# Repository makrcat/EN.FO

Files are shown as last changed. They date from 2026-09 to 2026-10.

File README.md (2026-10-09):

## outdoorsy-gadget

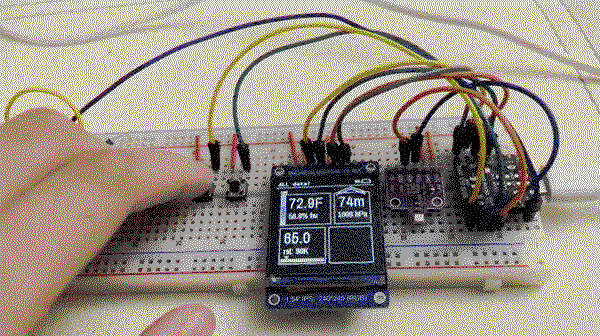
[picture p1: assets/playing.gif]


The **EN.FO** is a personal project for tracking the environment when outdoors. It measures altitude (pressure), temperature, humidity, and air quality through the BME680 chip. And it also has games now :3c

Around the end stages submitted to hack club stardance.

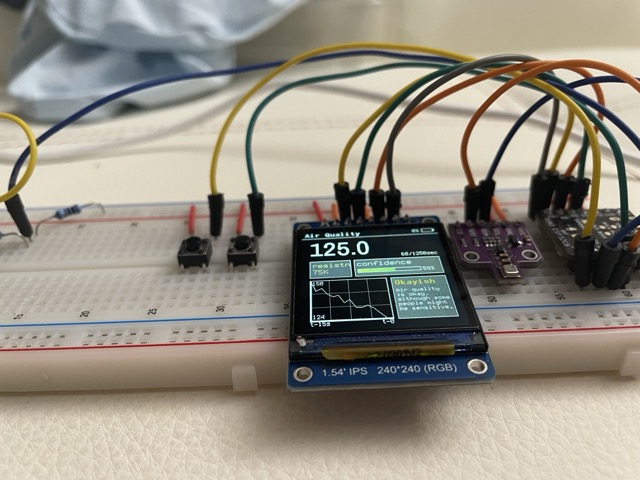
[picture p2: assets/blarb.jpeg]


## Why I made this

I found a BME680 in a store, and I'd seen people making these home weather station setups and using temperature sensors for their first projects. I thought it would be cool to be able to track the weather while outside too, like while hiking or going somewhere without wifi! 

It would be pretty neat to get momentary values from a sensor for the surrounding area instead of looking online.

## CAD models


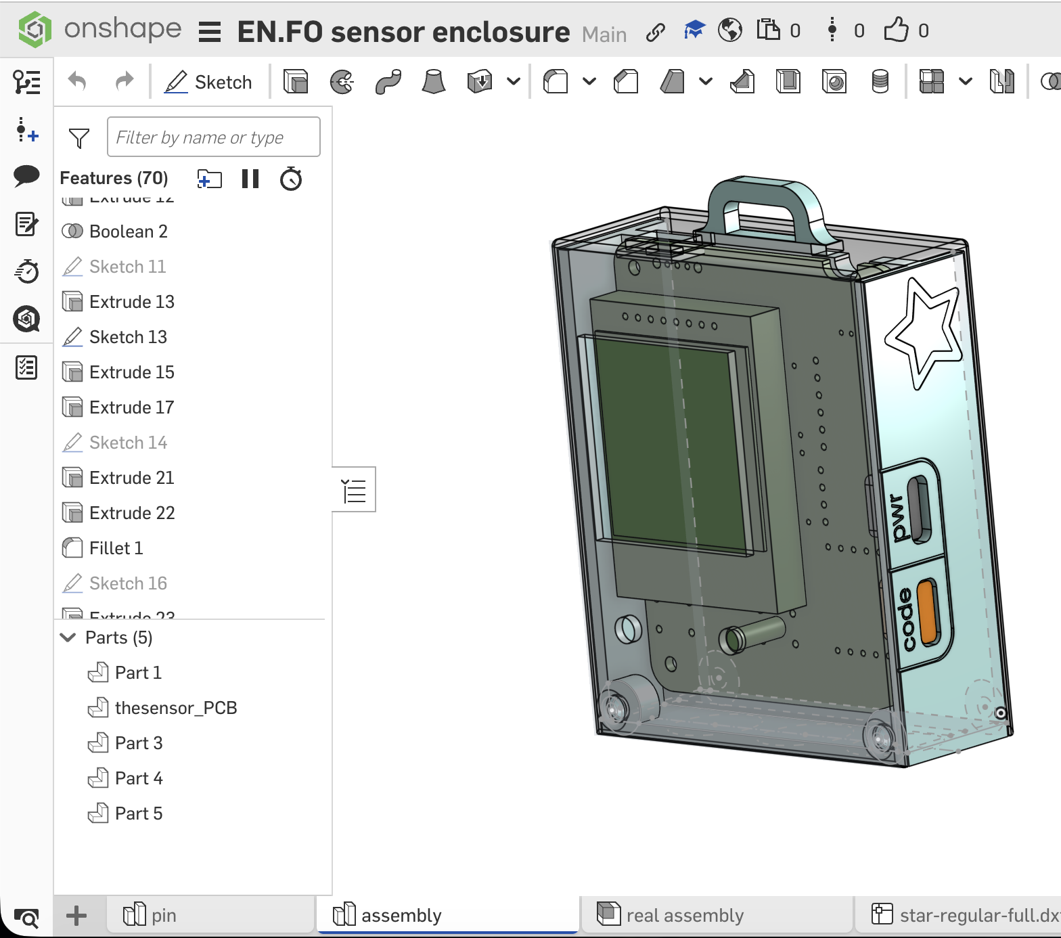
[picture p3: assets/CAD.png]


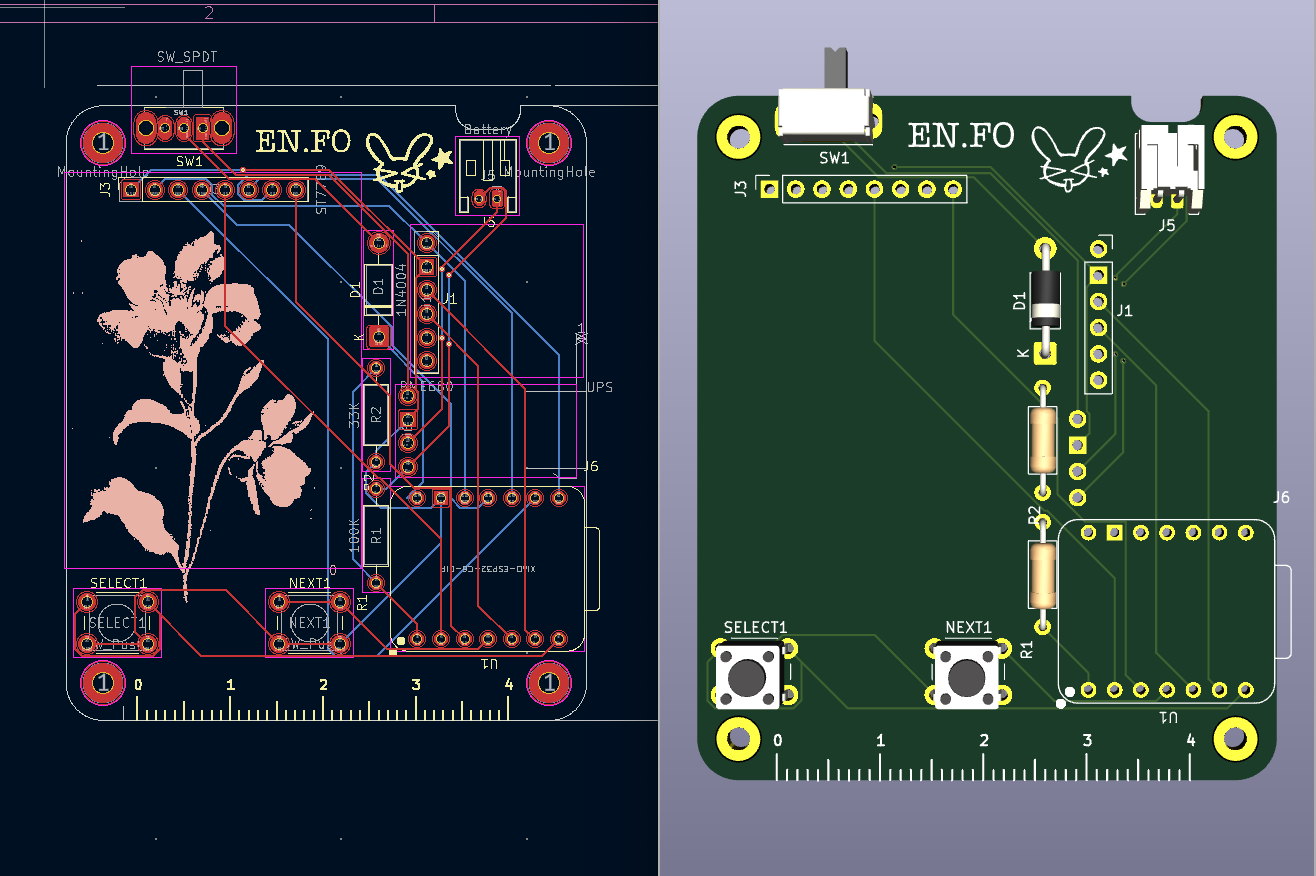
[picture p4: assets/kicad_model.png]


https://cad.onshape.com/documents/2de4779b51845175f3a3e786/w/7837df9d32ef23797361ec83/e/9a8511381228d62ac6592067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 

## Flashing to ESP32

**Materials:** 
- You want an esp32 with at least 512kb of RAM, or else it can't run the heavy graphics of circuitpython.
- You need a similar ST7789-driven screen, a microcontroller as specified above, and a bme680.
- Also, having a fuse would probably be good (just in case you short out components).

Install circuitpython! Then,

I use vscode to program, but I used Thonny to handle the flashing.
- Programs that go into the microcontroller are  `src`, `graphics`, `settings.json`, `logger.json`, and `fontsPCF`, side by side on root`/`. 
- You also have to install the libraries separately on Thonny, but it only takes a bit.

## In case you want to actually make one

Check if you are soldering the ESP-32 so that it's "bottom side up", or label-side up. The USB-C should be on the bottom. Same goes with the UPS module, make sure the USB-C is on the bottom. Or else you have to edit the CAD to match.

## Testing the program locally

I wanted to test the UI quickly, so the computer simulation is for that. The data is simulated in `mockIC.py`. 

`⚠️` Important note!! Open the `firmware` folder by itself! Otherwise, vscode will read the file paths incorrectly.

## Other images

This project originally started with a BMP & an e-ink, but gradually didn't work for the use case. I have a cool e-ink now, though.

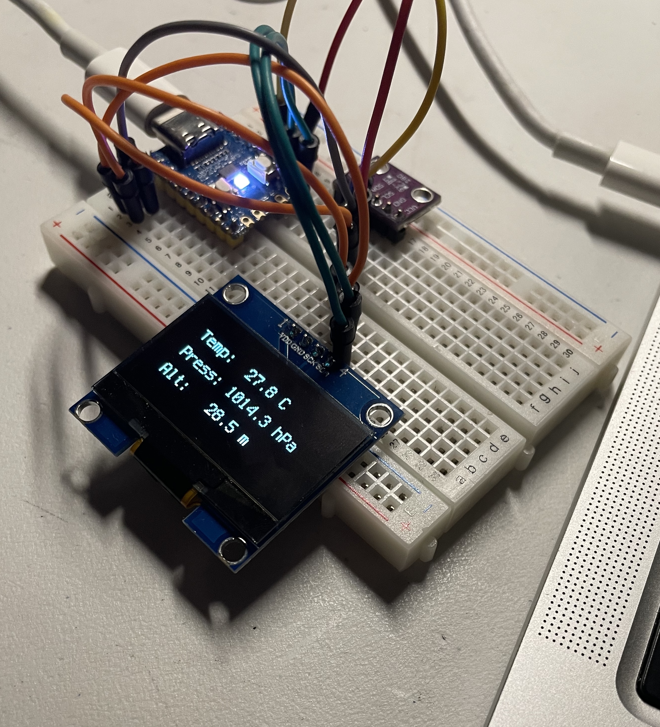
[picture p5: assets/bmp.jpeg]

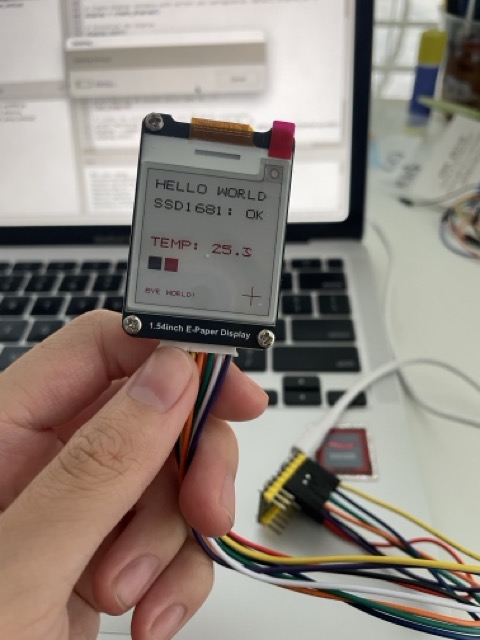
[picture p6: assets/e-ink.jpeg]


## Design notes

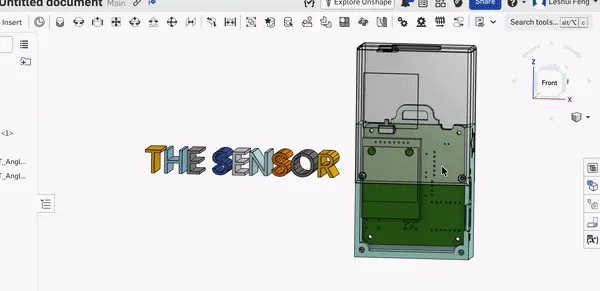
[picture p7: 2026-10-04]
assets/CADgif.webp

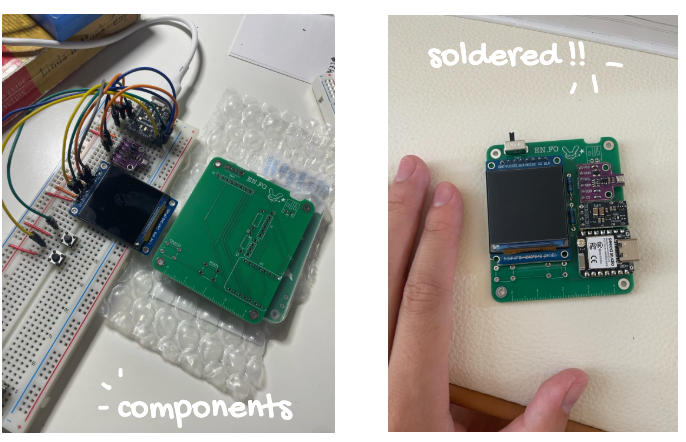
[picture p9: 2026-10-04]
2026_10_04_0o2_Kleki.png

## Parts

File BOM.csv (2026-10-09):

Item Name | Qty | Price (total) (USD) | Item link | Notes
replacement snips | 1 | $6.99 | https://www.amazon.com/HOUSERAN-Cutters-Cutting-Diagoanl-Jewelry/dp/B0FGXNMZNS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
soldering tips | 1 | $7.59 | https://www.amazon.com/AUSTOR-Pieces-Soldering-Cleaning-Station/dp/B07CTLZBHQ?c=ts&s=hi&ts_id=13837321 | My soldering tips are very used
PCB from PCBway | 1 | $53.61 |  | from PCBWAY
tube of E6000 | 1 | $9.99 | https://www.amazon.com/Eclectic-Products-Multi-Purpose-Waterproof-Paintable/dp/B07QHTBZZT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 | for gluging silicone cap to button
bme680 | 1 | $9.99 | https://www.amazon.com/Teyleten-Robot-Temperature-CJMCU-680-Development/dp/B0BZP7K17K | the bme680
esp32-c6 | 1
1.54inch 240x240 TFT LCD | 1
5v UPS power module mini | 1
1000 mAh LiPo (503450) | 1
silicone cap for buttons, a pack | 1
buttons (6x6x8? tbd), a bunch | 1
transparent petg | 1
the t.o.m.e HTPLA from protopasta | 1
Total Price (USD): | $88.17

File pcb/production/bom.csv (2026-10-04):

Designator | Footprint | Quantity | Value | LCSC Part #
J1 | PinSocket_1x06_P2.54mm_Vertical | 1 | BME680
J3 | PinSocket_1x08_P2.54mm_Vertical | 1 | ST7789
J5 | JST_PH_S2B-PH-K_1x02_P2.00mm_Horizontal | 1 | Battery
J6 | PinSocket_1x04_P2.54mm_Vertical | 1 | UPS
NEXT1, SELECT1 | SW_PUSH_6mm | 2 | SW_Push
R1 | R_Axial_DIN0207_L6.3mm_D2.5mm_P10.16mm_Horizontal | 1 | 100K
R2 | R_Axial_DIN0207_L6.3mm_D2.5mm_P10.16mm_Horizontal | 1 | 33K
SW1 | SW_Slide_SPDT_Angled_CK_OS102011MA1Q | 1 | SW_SPDT
U1 | XIAO-ESP32-C6-DIP | 1 | XIAO-ESP32-C6-DIP

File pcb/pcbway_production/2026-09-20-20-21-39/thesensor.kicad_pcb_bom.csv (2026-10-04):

Designator | Quantity | Value | Footprint | Package | MPN | DNP | Mount_Type | Description
J1 | 1 | BME680 | PinSocket_1x06_P2.54mm_Vertical |  |  |  | tht | Generic connector, single row, 01x06, script generated
J3 | 1 | ST7789 | PinSocket_1x08_P2.54mm_Vertical |  |  |  | tht | Generic connector, single row, 01x08, script generated
J5 | 1 | Battery | JST_PH_S2B-PH-K_1x02_P2.00mm_Horizontal |  |  |  | tht | Generic connector, single row, 01x02, script generated
J6 | 1 | UPS | PinSocket_1x04_P2.54mm_Vertical |  |  |  | tht | Generic connector, single row, 01x04, script generated
NEXT1, SELECT1 | 2 | SW_Push | SW_PUSH_6mm |  |  |  | tht | Push button switch, generic, two pins
R1 | 1 | 100K | R_Axial_DIN0207_L6.3mm_D2.5mm_P10.16mm_Horizontal |  |  |  | tht | Resistor
R2 | 1 | 33K | R_Axial_DIN0207_L6.3mm_D2.5mm_P10.16mm_Horizontal |  |  |  | tht | Resistor
SW1 | 1 | SW_SPDT | SW_Slide_SPDT_Angled_CK_OS102011MA1Q |  |  |  | tht | Switch, single pole double throw
U1 | 1 | XIAO-ESP32-C6-DIP | XIAO-ESP32-C6-DIP |  |  |  | smt

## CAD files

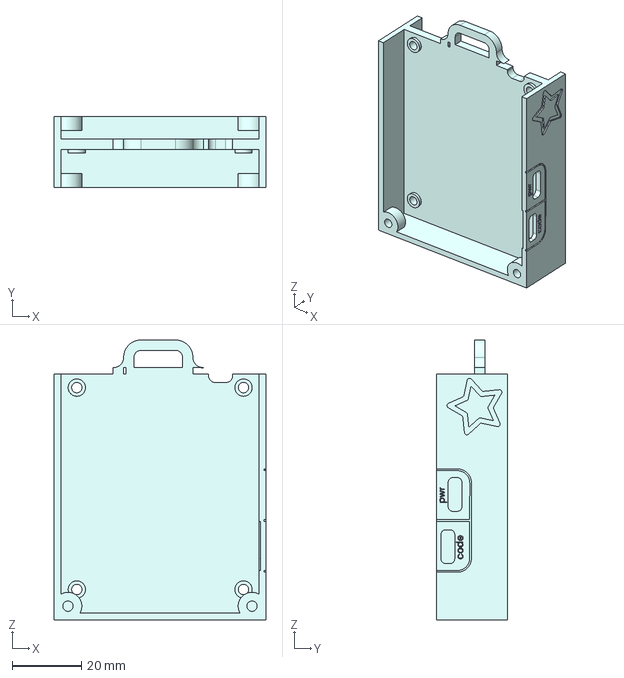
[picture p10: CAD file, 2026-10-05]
cad/innercasing.step
61.1 x 20.5 x 80.9 mm

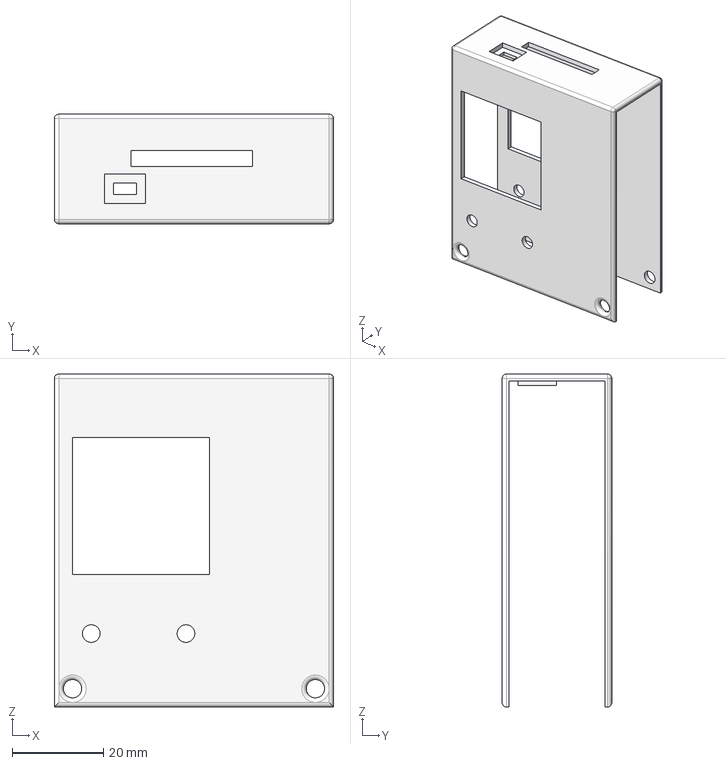
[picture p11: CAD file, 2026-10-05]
cad/outercasing.step
61.1 x 24.0 x 72.8 mm

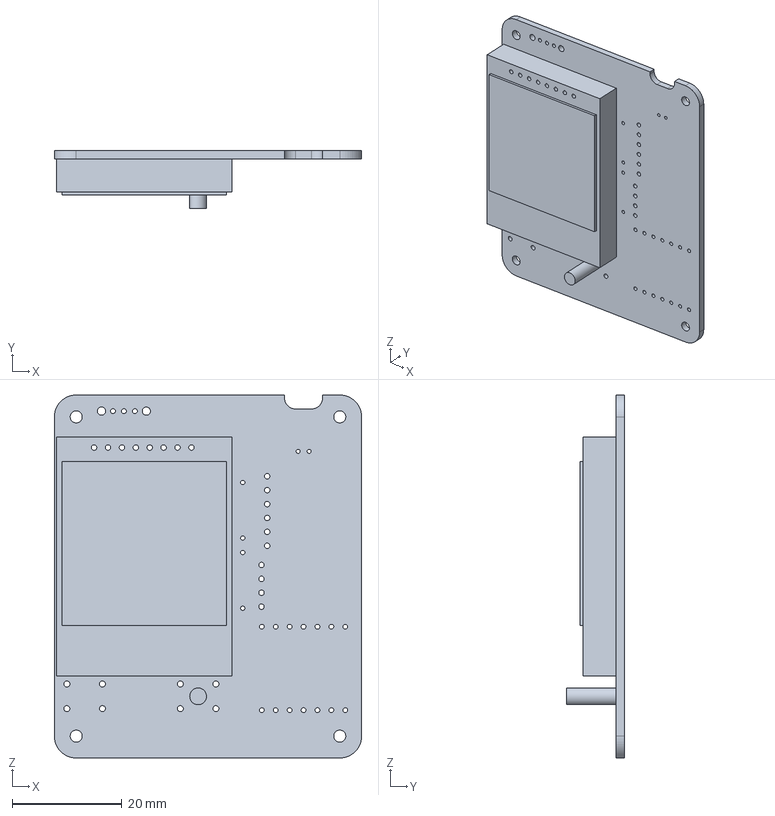
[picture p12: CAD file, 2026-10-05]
cad/barepcb.step
56.1 x 10.5 x 66.3 mm

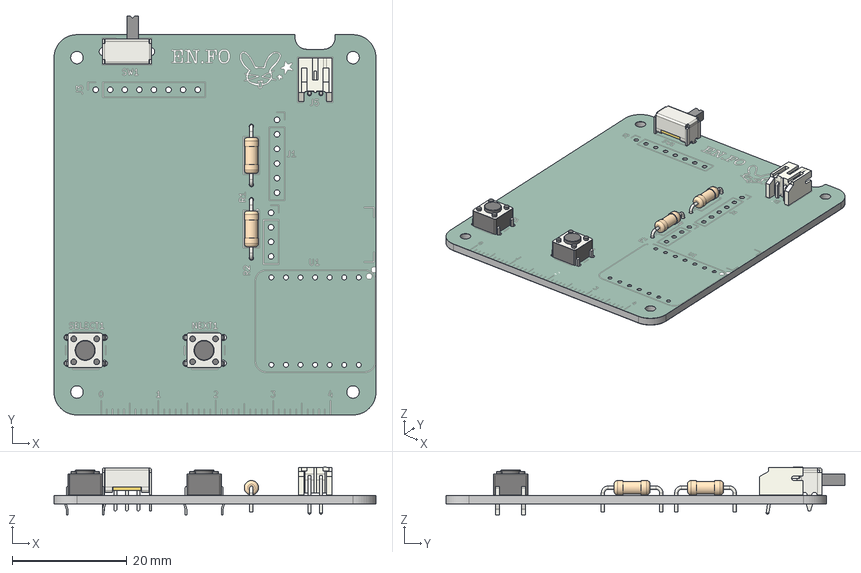
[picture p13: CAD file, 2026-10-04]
cad/thesensor.step
56.1 x 69.5 x 8.35 mm
R_Axial_DIN0207_L6.3mm_D2.5mm_P10.16mm_Horizontal x 2
SW_PUSH_6mm x 2
SW_Slide_SPDT_Angled_CK_OS102011MA1Q
JST_PH_S2B-PH-K_1x02_P2.00mm_Horizontal
thesensor_silkscreen x 2
thesensor_soldermask x 2
thesensor_PCB

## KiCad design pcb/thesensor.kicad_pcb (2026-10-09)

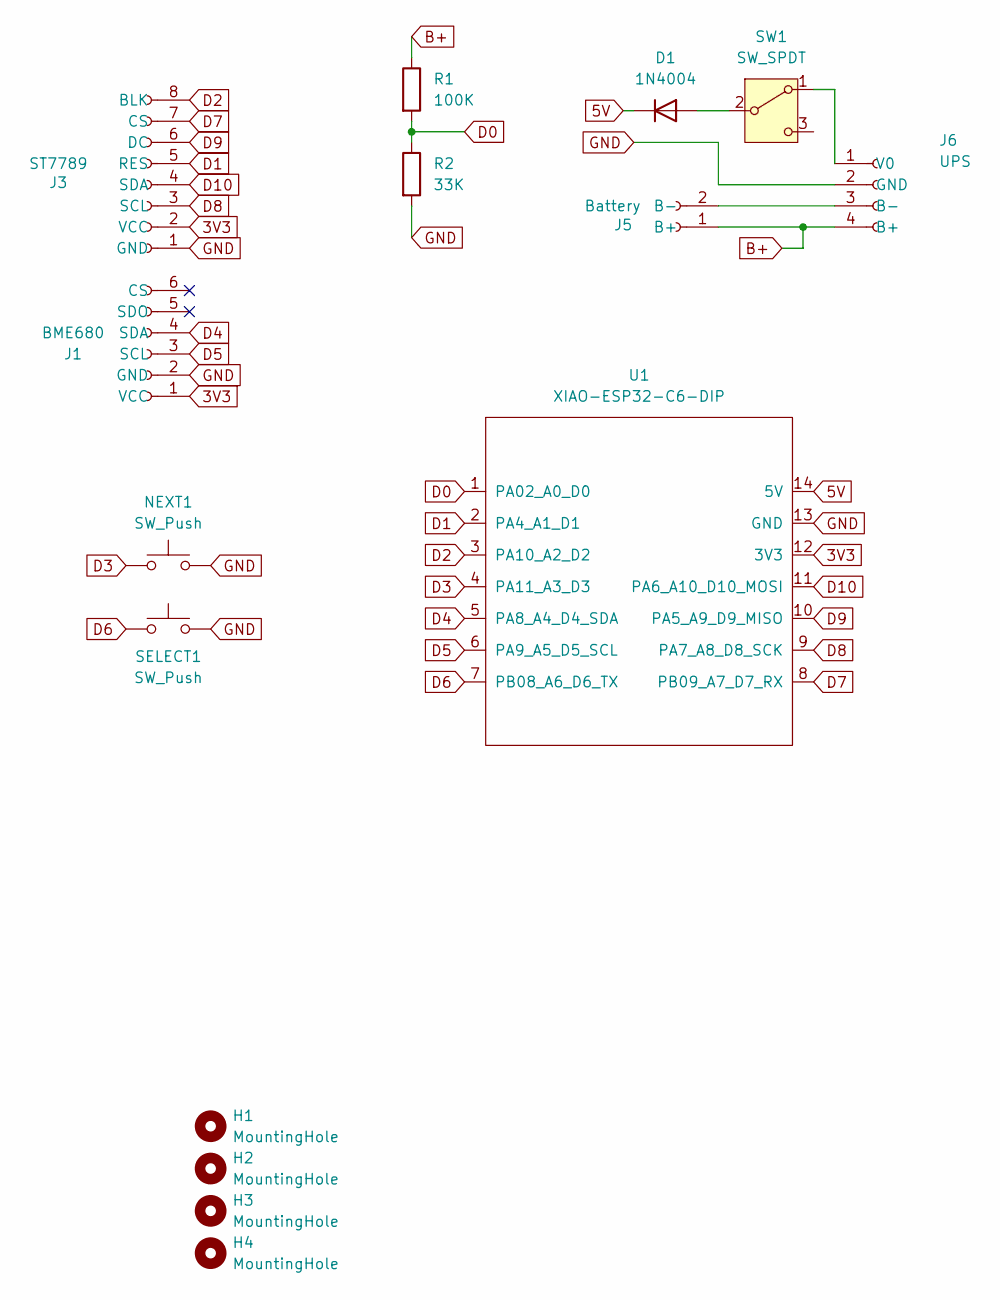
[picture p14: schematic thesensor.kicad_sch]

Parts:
D1: 1N4004; D_DO-41_SOD81_P10.16mm_Horizontal
H1, H2, H3, H4: MountingHole; MountingHole_2.2mm_M2_Pad
J1: BME680; PinSocket_1x06_P2.54mm_Vertical
J3: ST7789; PinSocket_1x08_P2.54mm_Vertical
J5: Battery; JST_PH_S2B-PH-K_1x02_P2.00mm_Horizontal
J6: UPS; PinSocket_1x04_P2.54mm_Vertical
NEXT1: SW_Push; SW_PUSH_6mm
R1: 100K; R_Axial_DIN0207_L6.3mm_D2.5mm_P10.16mm_Horizontal
R2: 33K; R_Axial_DIN0207_L6.3mm_D2.5mm_P10.16mm_Horizontal
SELECT1: SW_Push; SW_PUSH_6mm
SW1: SW_SPDT; SW_Slide_SPDT_Angled_CK_OS102011MA1Q
U1: XIAO-ESP32-C6-DIP

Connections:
3V3: J1.1 (VCC), J3.2 (VCC), U1.12 (3V3)
5V: D1.1 (K), U1.14 (5V)
B+: J5.1 (B+), J6.4 (B+), R1.1
D0: R1.2, R2.1, U1.1 (PA02_A0_D0)
D1: J3.5 (RES), U1.2 (PA4_A1_D1)
D2: J3.8 (BLK), U1.3 (PA10_A2_D2)
D3: NEXT1.1, U1.4 (PA11_A3_D3)
D4: J1.4 (SDA), U1.5 (PA8_A4_D4_SDA)
D5: J1.3 (SCL), U1.6 (PA9_A5_D5_SCL)
D6: SELECT1.1, U1.7 (PB08_A6_D6_TX)
D7: J3.7 (CS), U1.8 (PB09_A7_D7_RX)
D8: J3.3 (SCL), U1.9 (PA7_A8_D8_SCK)
D9: J3.6 (DC), U1.10 (PA5_A9_D9_MISO)
D10: J3.4 (SDA), U1.11 (PA6_A10_D10_MOSI)
GND: J1.2 (GND), J3.1 (GND), J6.2 (GND), NEXT1.2, R2.2, SELECT1.2, U1.13 (GND)
unnamed: D1.2 (A), SW1.2 (B)
unnamed: J5.2 (B-), J6.3 (B-)
unnamed: J6.1 (V0), SW1.1 (A)

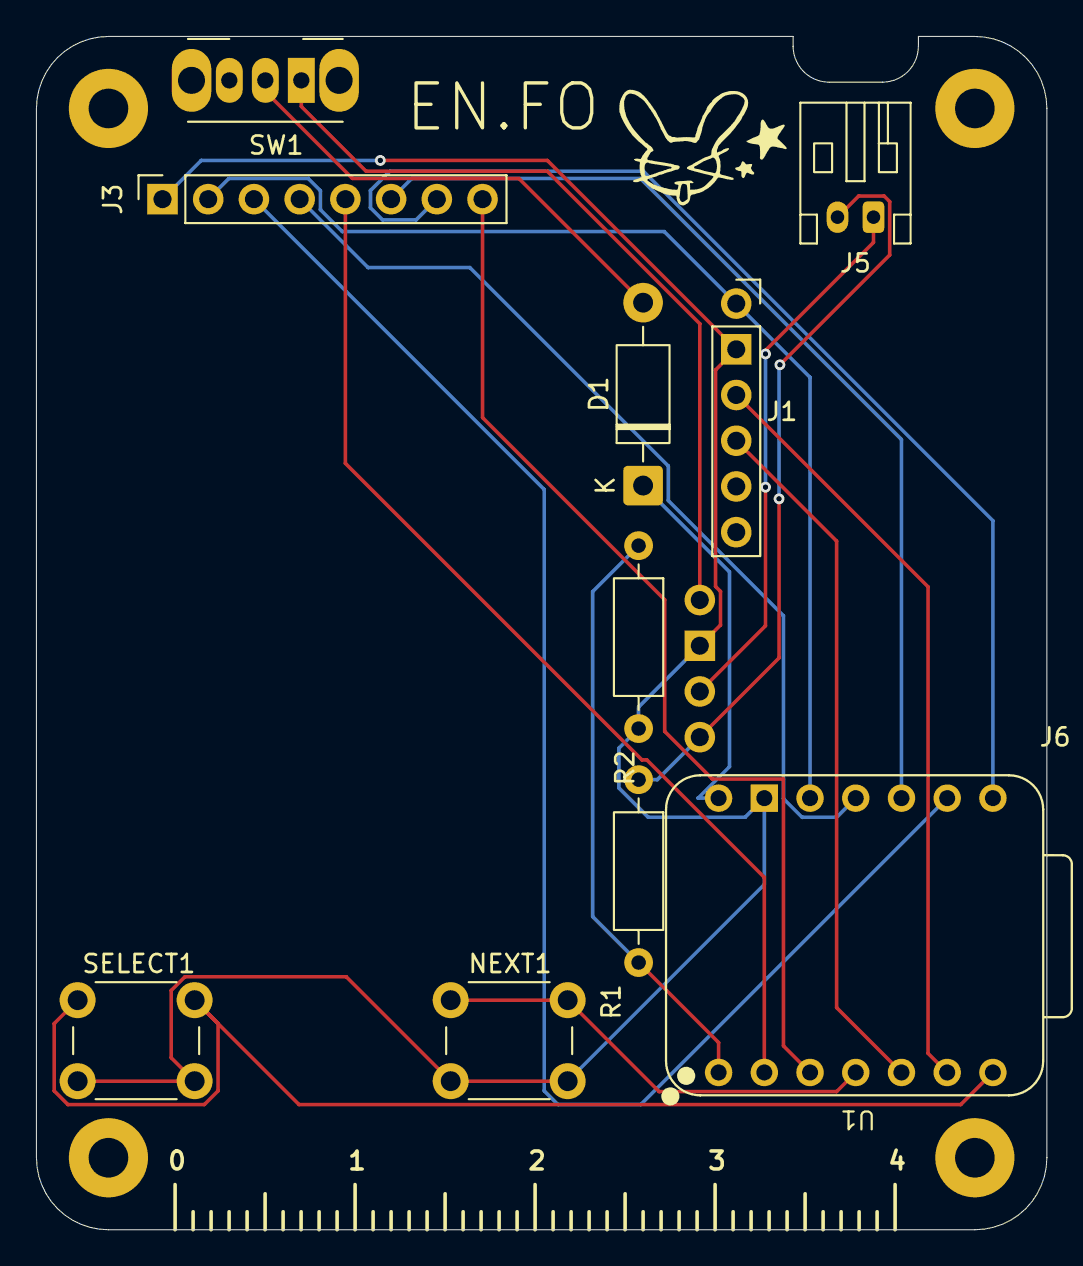
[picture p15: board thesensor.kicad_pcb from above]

Board: 2 copper layers, 56.1 x 66.3 mm, 15 parts (0 on the bottom side), 18 nets.

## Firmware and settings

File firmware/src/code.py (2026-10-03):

import displayio, digitalio
from my_utilities import *

# import board, busio
from Page import *
from PacManPage import PacManPage


from adafruit_display_shapes.line import Line
from mockIC import MockBME680
import time
from DashboardPage import DashboardPage
from TemperaturePage import TemperaturePage
from PressurePage import PressurePage
from AQIPage import AQIPage
from SettingsPage import SettingsPage
from LoggerPage import LoggerPage
from SnakePage import SnakePage
from battery import Battery
from Game2048Page import Game2048Page

time.sleep(1.0) 
import gc
gc.collect()

displayio.release_displays()

display = None
bme680 = None
next_button = None
select_button = None
battery_pin = None


COMPUTER = True


if COMPUTER:
    import pygame
    from blinka_displayio_pygamedisplay import PyGameDisplay

    display = PyGameDisplay(240, 240)
    display.auto_refresh = False

    bme680 = MockBME680()
    bme680.sea_level_pressure = 1017.9
        


else:
    import board, busio
    from fourwire import FourWire
    import adafruit_bme680
    import adafruit_st7789
    import analogio


    next_button = digitalio.DigitalInOut(board.D3) #14
    next_button.switch_to_input(pull=digitalio.Pull.UP)
    select_button = digitalio.DigitalInOut(board.D6) #26
    select_button.switch_to_input(pull=digitalio.Pull.UP)
    
    battery_pin = analogio.AnalogIn(board.A0)


    i2c_sensor = busio.I2C(
        scl=board.D5,
        sda=board.D4,
        frequency=100_000
    ) #400


    bme680 = adafruit_bme680.Adafruit_BME680_I2C(i2c_sensor, address=0x77) 
    bme680.sea_level_pressure = 1017.9

    spi = busio.SPI(clock=board.D8, MOSI=board.D10)

    display_bus = FourWire(
        spi, 
        command=board.D9, 
        chip_select=board.D7, 
        reset=None  
    )

    display = adafruit_st7789.ST7789(
        display_bus, 
        width=240, 
        height=240, 
        rowstart=80,
        rotation=180
    )


def get_voltage():
    global battery_pin, COMPUTER
    
    if not COMPUTER:
        pv = battery_pin.value / 65535 * 3.7
        return pv * 2.0
    else:
        return 3.3


data_store = DataStore(bme680)
data_store.load_settings()

### DISPLAY STUFF
master_group = displayio.Group()
display.root_group = master_group


HEADER_HEIGHT = 20
# permanent black background
color_palette = displayio.Palette(1)
color_palette[0] = 0x000000
bg_bitmap = displayio.Bitmap(display.width, display.height, 1)
bg_tilegrid = displayio.TileGrid(bg_bitmap, pixel_shader=color_palette)
bg_line = Line(x0=0, y0=HEADER_HEIGHT, x1=display.width, y1=HEADER_HEIGHT, color=0xFFFFFF)

master_group.append(bg_tilegrid)
master_group.append(bg_line)


# bat group is premanently outside of the content group it's async updated
# do i really know waht async means not really
# its updated silently with other updates
battery_widget = Battery(master_group, display.width)


content_group = displayio.Group()
master_group.append(content_group)



### PAGE ARCHITECTURE ###


PAGE_CLASSES = [
    DashboardPage,
    TemperaturePage,
    PressurePage,
    AQIPage,
    LoggerPage,
    SettingsPage,
    SnakePage,
    PacManPage,
    Game2048Page,
]

page_index = 8
current_page = None
SELECT_DOWN_ON_PRESS = False


def release_page():
    global current_page
    if current_page is None:
        return
    if type(current_page).__name__ == "SettingsPage":
        if current_page.needs_write_update():
            data_store.save_settings()

    while len(content_group) > 0:
        g = content_group[len(content_group) - 1]
        while len(g) > 0:
            g.pop()
        content_group.pop()

    # drop every attribute so nothing is kept alive through the page object
    for name in dir(current_page):
        if not name.startswith("__"):
            try:
                setattr(current_page, name, None)
            except Exception:
                pass
    current_page = None
    
    

def show_page(idx):
    global current_page, SELECT_DOWN_ON_PRESS, COMPUTER

    global current_page, SELECT_DOWN_ON_PRESS
    gc.collect()
    # print("pre-build", gc.mem_free())
    current_page = PAGE_CLASSES[idx](data_store)

    # select behavior depends on the NEW page
    selectDownOnPressPages = ["SnakePage", "PacManPage"]
    SELECT_DOWN_ON_PRESS = type(current_page).__name__ in selectDownOnPressPages

    current_page.on_show()
    content_group.append(current_page.group)

    if not current_page.ignore_sensor:
        current_page.update_page()

    display.refresh()
    gc.collect()
    
    if not COMPUTER: print(type(current_page).__name__, gc.mem_free())

    

def pagers():
    global page_index
    page_index = (page_index + 1) % len(PAGE_CLASSES) 
    show_page(page_index)

def global_init():
    data_store.update()
    show_page(page_index)

global_init()

last_sensor_read = 0 # bug fixed










next_button_pressed_last = False
select_button_pressed_last = False
SMODE = False

NMODE = False
L_SMODE = False
select_time_start_down = 0
long_press_fired = False # prevent the long press always being written True while pressed
long_thresh = 1.5





def handle_buttons_modes():
    global next_button_pressed_last, select_button_pressed_last
    global NMODE, SMODE, L_SMODE, select_time_start_down, long_thresh, long_press_fired
    global SELECT_DOWN_ON_PRESS
    
    next_button_pressed = not next_button.value
    select_button_pressed = not select_button.value

    NMODE = False
    SMODE = False
    L_SMODE = False
    
    if select_button_pressed and not select_button_pressed_last: 
        select_time_start_down = time.monotonic()
        long_press_fired = False
        if SELECT_DOWN_ON_PRESS:
            SMODE = True
        
    elif select_button_pressed:
        if (not long_press_fired) and time.monotonic() - select_time_start_down >= long_thresh:
            L_SMODE = True
            long_press_fired = True
            
    elif (select_button_pressed_last and not select_button_pressed 
          and time.monotonic() - select_time_start_down < long_thresh):
        if not SELECT_DOWN_ON_PRESS:
            SMODE = True
        
    if next_button_pressed and not next_button_pressed_last:
        NMODE = True
        
    next_button_pressed_last = next_button_pressed
    select_button_pressed_last = select_button_pressed
    
# Gemini-generated ####
def handle_buttons_modes_computer():
    global next_button_pressed_last, select_button_pressed_last
    global NMODE, SMODE, L_SMODE, select_time_start_down, long_thresh, long_press_fired
    
    NMODE = False
    SMODE = False
    L_SMODE = False

    # PYGAME window events (handles closing the window properly)
    for event in pygame.event.get():
        if event.type == pygame.QUIT:
            pygame.quit()
            raise SystemExit

    # Poll keyboard state continuously (similar to reading hardware pins)
    keys = pygame.key.get_pressed()
    next_button_pressed = keys[pygame.K_n] or keys[pygame.K_RIGHT]
    select_button_pressed = keys[pygame.K_s] or keys[pygame.K_RETURN]


    if select_button_pressed and not select_button_pressed_last: 
        select_time_start_down = time.monotonic()
        long_press_fired = False
        if SELECT_DOWN_ON_PRESS:
            SMODE = True
        
    elif select_button_pressed:
        if (not long_press_fired) and time.monotonic() - select_time_start_down >= long_thresh:
            L_SMODE = True
            long_press_fired = True
            
    elif (select_button_pressed_last and not select_button_pressed 
          and time.monotonic() - select_time_start_down < long_thresh):
        
        if not SELECT_DOWN_ON_PRESS: # select if it is after press
            SMODE = True
        

    if next_button_pressed and not next_button_pressed_last:
        NMODE = True
        
    next_button_pressed_last = next_button_pressed
    select_button_pressed_last = select_button_pressed
#########################



last_gc_time = 0
GC_INTERVAL = 1.0
upd = False

while True:

    if COMPUTER: handle_buttons_modes_computer()
    else: handle_buttons_modes()

    now = time.monotonic()

    if now - last_gc_time > GC_INTERVAL:
        #print("Free RAM:", gc.mem_free(), "bytes")
        gc.collect()
        last_gc_time = now
        #print(gc.mem_free(), gc.mem_alloc())
        
    if current_page.otherIdleUpdates:
        upd = current_page.should_update()

    if now - last_sensor_read >= data_store.get_setting("interval"):
        data_store.update()
        
        last_sensor_read = now
        if not current_page.ignore_sensor:
            current_page.data_schedule_update()
            upd = True

    if NMODE:
        if current_page.on_short_next() != False:
            release_page()
            gc.collect()
            pagers()
        else:
            upd = True

    elif SMODE:
        current_page.on_short_select()
        upd = True

    elif L_SMODE:
        current_page.on_long_select()
        upd = True

    if upd:
        current_page.update_page()
        upd = False
        
        battery_widget.update(get_voltage())
        gc.collect()
        display.refresh()

    time.sleep(0.01)

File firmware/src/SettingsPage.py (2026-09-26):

import displayio
import terminalio
from my_utilities import *
from Page import Page
from adafruit_display_shapes.line import Line
from adafruit_display_text import label
from adafruit_display_shapes.rect import Rect
from fonts import NINE


class Selector(displayio.Group):
    def __init__(self, x, y, width, height, parent):
        super().__init__(x=x, y=y)
        self.width = width
        self.height = height
        self.parent = parent
        
        self.bg_rect = Rect(0, 0, width, height, fill=0x444444, outline=0xFFFFFF)
        self.append(self.bg_rect)
    

    def on_focus(self):
        self.bg_rect.outline = 0xFF0000
        
    def on_defocus(self):
        self.bg_rect.outline = 0xFFFFFF
        
    def on_select(self):
        pass

    def get_value(self):
        return None
    

class NumberSelector(Selector):
    def __init__(self, x, y, width, height, parent, min=None):
        super().__init__(x=x, y=y, width=width, height=height, parent=parent)
        self.current_val = 0
        
        self.label = label.Label(
            NINE, 
            text=str(self.current_val), 
            color=0xFFFFFF, 
            anchor_point=(0.5, 0.5), 
            anchored_position=(width // 2, height // 2)
        )
        self.append(self.label)
        
        self.min = min
        
    def on_select(self):
        self.current_val += 1
        if self.current_val > 9:
            
            if self.min != None:
                self.current_val = self.min
            else:
                self.current_val = 0
            
        self.label.text = str(self.current_val)
        
    def get_value(self):
        return self.current_val
    
    def set_selected(self, u):
        if 0 <= u <= 9:
            self.current_val = u
            self.label.text = str(self.current_val)
    

class StringSelector(Selector):
    def __init__(self, x, y, width, height, unitsList, parent):
        super().__init__(x=x, y=y, width=width, height=height, parent=parent)
        
        self.current_index = 0
        self.unitsList = unitsList
        
        self.label = label.Label(
            NINE, 
            text=str(self.unitsList[self.current_index]), 
            color=0xFFFFFF, 
            anchor_point=(0.5, 0.5), 
            anchored_position=(width // 2, height // 2)
        )
        self.append(self.label)
        
    def on_select(self):
        self.current_index += 1
        if self.current_index >= len(self.unitsList):
            self.current_index = 0
            
        self.label.text = self.unitsList[self.current_index]
        
    def get_value(self):
        return self.unitsList[self.current_index]
    
    def set_selected(self, u):
        if u in self.unitsList:
            self.current_index = self.unitsList.index(u)
            self.label.text = self.unitsList[self.current_index]


class IntervalGroup(displayio.Group):
    def __init__(self, x, y, width, height, store):
        super().__init__(x=x, y=y)
        self.width = width
        self.height = height
        self.store = store

        self.append(label.Label(NINE, text="interval:", color=0xFFFFFF, 
            anchor_point=(0.0, 0.0),  anchored_position=(0, 0)))
        
        self.tens = NumberSelector(x=180, y=0, width=14, height=20, parent=self)
        self.ones = NumberSelector(x=195, y=0, width=14, height=20, parent=self, min=1)
        
        self.append(self.tens)
        self.append(self.ones)
        
        self.append(label.Label(NINE, text="s", color=0xFFFFFF, 
            anchor_point=(0.0, 0.0),  
            anchored_position=(195 + 16, 1), scale=1))
        
        self._load()
            
    def _load(self):
        interval_val = self.store.get_setting("interval") or 0
        self.tens.set_selected(int(interval_val // 10))
        self.ones.set_selected(int(interval_val % 10))
        
    def update_value(self, store):
        tens = self.tens.get_value()
        ones = self.ones.get_value()
        result = 10 * int(tens) + int(ones)
        store.set_setting("interval", result)
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

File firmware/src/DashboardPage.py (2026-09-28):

import displayio, terminalio
from my_utilities import *
from Page import Page
from adafruit_display_shapes.rect import Rect
from adafruit_display_shapes.triangle import Triangle
from adafruit_display_text import label
from fonts import PRAGATI_22, PRAGATI_42


class TempBox(displayio.Group):
    def __init__(self, x, y):
        super().__init__(x=x, y=y)
        
        self.append(Rect(0, 0, 122, 84, outline=0xFFFFFF))
        
        self.temp_label = label.Label(
            PRAGATI_42, 
            text="--.-", 
            color=0xFFFFFF, 
            anchor_point=(0.0, 0.0),
            anchored_position=(20, 12), 
            scale=1
        )
        self.hum_label = label.Label(
            PRAGATI_22, 
            text="-- hu", 
            color=0xFFFFFF, 
            anchor_point=(0.0, 0.0),
            anchored_position=(20, 52), 
            scale=1
        )
        self.append(self.temp_label)
        self.append(self.hum_label)
        
        self.gradient = tempGradientObject(xpos=0, ypos=0, width=12, height=84, pc=0.5, 
                                           colorz=[0x0FEFD8, 0xC300FF, 0xFF0000], group=self)
        self.append(Rect(0, 0, 12, 84, outline=0xFFFFFF))
        
        # Axis labels
        self.temp_top_label = label.Label(terminalio.FONT, text='x', color=0xFFFFFF, anchor_point = (0.5, 0.5),
                                          anchored_position=(7, -6), scale=1)
        self.append(self.temp_top_label)
        self.temp_bottom_label = label.Label(terminalio.FONT, text='0', color=0xFFFFFF,  anchor_point = (0.5, 0.5),
                                          anchored_position=(7, 76), scale=1)
        self.append(self.temp_bottom_label)
        
        self.last_temp_unit = None

    def update(self, store):
        temp_con = store.getConvertedVal("temperature")
        temp_unit = store.get_setting("temperature_unit")
        self.temp_label.text = f"{temp_con:.1f}"+ temp_unit
        self.hum_label.text = f"{store.getVal("humidity"):.1f}% hu"
        
        max = 100 if temp_unit == 'F' else (37.8 if temp_unit == 'C' else 310.95)
        min = 32 if temp_unit == 'F' else (0 if temp_unit == 'C' else 273.15)
        self.gradient.update((temp_con - min) / (max - min))
        
        if self.last_temp_unit != temp_unit:
            self.temp_top_label.text = str(max)
            self.temp_bottom_label.text = str(min)
            self.last_temp_unit = temp_unit

class GasBox(displayio.Group):
    def __init__(self, x, y):
        super().__init__(x=x, y=y)
        
        self.append(Rect(0, 0, 108, 90, outline=0xFFFFFF))
        
        self.aqi_label = label.Label(
            PRAGATI_42, 
            text="--.-", 
            color=0xFFFFFF, 
            anchor_point=(0.0, 0.0),
            anchored_position=(10, 12),
            scale=1
        )

        
        self.resistance_label = label.Label(
            PRAGATI_22, 
            text="--.-", 
            color=0xFFFFFF, 
            anchor_point=(0.0, 0.0), 
            anchored_position=(10, 52),
            scale=1
        )

        self.append(self.aqi_label)
        self.append(self.resistance_label)

        self.gradient = tempGradientObject(
            xpos=4, ypos=78, width=100, height=7,pc=1.0, group=self, 
            colorz=[0x31D726, 0xE6C329, 0xDF752F, 0xDB2424, 0x892ADC], 
            orientation='horizontal'
        )
        
        
        self.pointer_group = displayio.Group()
        pointer_shape = Triangle(0, 4, -4, 0, 4, 0, fill=0xFFFFFF)
        self.pointer_group.append(pointer_shape)
        self.pointer_group.y = 71
        self.pointer_group.x = 4
        self.append(self.pointer_group)
        
        
        self.append(Rect(4, 78, 100, 7, outline=0xFFFFFF))

    def update(self, store):
        aqi = store.getVal("aqi")
        self.aqi_label.text = f"{aqi:.1f}"
        self.resistance_label.text = f"rst: {(store.getVal("gas_resistance")/1000):.0f}K"
        
        constrained_aqi = max(0.0, min(aqi, 500.0))
        self.pointer_group.x = 4 + int((constrained_aqi / 500.0) * 100)
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

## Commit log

2026-09-18 fix memory leak? (also esp32 migration has worked yay)
    [code.py]
2026-09-26 fixed data sensor interval 00seconds thing -> 01 seconds
    [LoggerPage.py, SettingsPage.py, theme.py]
2026-10-04 reorder files
    [BOM.csv, bom.csv, designators.csv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]
2026-10-04 add to BOM.csv
    [BOM.csv]
2026-10-04 update bom
    [BOM.csv]
2026-10-05 add .step files
    [barepcb.step, innercasing.step, outercasing.step]
2026-10-05 added cad image
2026-10-08 overhaul the schematic and change pcb a bit
    [thesensor.kicad_pcb, thesensor.kicad_sch]
2026-10-09 edit pcb, update readme
    [BOM.csv, thesensor.kicad_pcb]
